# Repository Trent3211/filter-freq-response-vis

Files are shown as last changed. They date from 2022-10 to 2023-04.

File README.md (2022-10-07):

# Filter Frequency Response Visualizer
GitHub repo for SDSU Senior Design Team 18, Filter Frequency Response Visualizer, or FFRV

## SYSTEM DESCRIPTION

The FFRV system  will be a test box used for measuring the frequency response of a user-provided passive filter. Once started, the system will apply a frequency sweep across an inputted filter, then measure the filter output gain and phase shift using analog computations, inputted to an Arduino Due microcontroller. Thus, this FFRV system will calculate the Bode plots for a real-world filter. The purpose of the FFRV system is to allow students, hobbyists, and other casual filter-designers a rapid way to gain insight into simple filters, such as what frequencies they pass or reject. As such, the FFRV system will be designed to be straightforward to use. It shall have a box face with only a select few clearly-labeled inputs, and output a data file of the measurements to the user computer, connected over USB to the test box. The functional components in this system will include a procured waveform generator, a PCB for distributing power and performing analog analysis on filter magnitude and phase, an Arduino Due for converting the analog values to digital and controlling the waveform generator, and a NET application which will provide the user an interface to work with the system.

## USING GITHUB

### Basic Operation: 

Git is both local version control (local) and also cloud version control (remote). Version control is logging how changes are made to documents (think google docs history) so that way changes can be managed. This is useful in code, where you may have a working solution but you want to add features to it, so "committing" that version to a history log allows you to make changes, and always have a successful solution to return to. Basically, git is a way to log changes you make files, and then upload them to the cloud (have them stored virtually, rather than locally). That's the basic operation. There is more features that will be used, but at its most basic operation its changing files and then logging those changes. 

### Install Git:

__Create Git Repo Folder__
<br>
Purely for containment sakes, you may want to create a folder for holding all your GitHub repos. This is optional. If you already have a folder, then you have no need to create a new folder. I (Trent) would suggest creating a folder titled "GitHub-Repos" in your Documents folder on your computer. You can create that folder using the following CLI commands. (To open the terminal, type "Command Prompt" in the search function on your windows machine, then click on the application)
```
cd Documents
mkdir GitHub-Repos
cd GitHub-Repos
```
__Add the repository__
<br>
Go to the desired directory (if you followed the steps in "Create Git Repo Folder", you will already be in the desired folder) and clone the repository. The comand will look like the following
```
git clone https://github.com/Trent3211/filter-freq-response-vis.git <Optional: What you'd like the document to be named>
```
Sections wrapped by \< \> will want to be replaced by what is referred to in the section. You should be able to now see a folder with the title you provided in the `<Optional: ...>` section, or it will be titled filter-freq-reponse-vis. You can view this in your file explorer, or by using the `dir` command in the Terminal (Command Prompt). To verify that the repository was properly imported, open the folder using the Windows File explorer. Check the folder for the README.md file. Its contents should match this file. 

### Creating a commit: 

To use Git, you'll link your local to the remote. As you make changes to the whatever files you're editing (NET application, INO file, KiCAD schematic, LTSpice simulation, etc.) you'll want to mark good changes. You mark these changes with a "commit". Committing works in three phases. First, you add the files you want to a new commit (using command line interface arguments, or CLI). Second, you'll "commit" these changes to your local git with a message that describes the changes that we're made from the previous commit to the current commit (there is a standardized way for creating commit messages), using the CLI. Third, you will "push" your local changes to the remote, again using the CLI. The steps and their associated CLI arguments are shown below:
<br>

__0a) Go to repository:__ `cd <local file path for github repo> `
<br>
__0b) Pull any new changes:__ `git fetch`
<br>
__1) Add Files:__ `git add <file name1> <file name2> ... <file name x> `
<br>
-> NOTE: Use `git status` to see what changes you've made to files. Those that have been edited will appear in red. After you've added them, if you run `git status` again they should appear green.
<br>
__2) Create Log Message:__ `git commit `
<br>
-> NOTE: This will open the default text editor, "Vim". Vim slightly terrifies me, so I would recommend switching your default editor to Notepad. To set it to that text editor, see "Other Helpful CLI". See notes on creating an effective commit message in the section below
<br>
__3) Push Changes:__ `git push -u origin`
<br>
-> NOTE: origin refers to the cloud repository, as it is the first instantiation of the github repo. 
<br>
<br>
_Commit Message Best Practice_
<br>
There are two parts to a commit message: the subject header and a description. A subject header should encapsulate what was changed in the commit using 50 characters or less. If there is a lot more detail necessary to encapsulate the full picture, that's what the description is used for. Best practice for the subject header is to use the imperative tense. Examples include `Test new data`, or `Rewire ground and power planes`. A subject header should be formatted such that someone reading could read it as "If applied, this commit will ...", followed by the subject header. Thus, the following examples would read "This commit will: Test new data" or "This commit will: Rewire ground and power planes". 
<br>
After writing the subject header, two lines breaks will separate the subject header from the description. The description may add more detail not included in the subject header, reasoning for why the commit was needed, include details about testing and verification steps, or detail errors that were encountered with the version in the commit that will need to be fixed in future commits. Wrap each line of the description after 72 characters, otherwise it will be hard to read using the CLI. More detail on commit messages can be found here [https://gist.github.com/robertpainsi/b632364184e70900af4ab688decf6f53]. A good commit message may look like the following (the sections preceded by # are autogenerated by Git. They can be left in, they will not be included when viewing the message in the future):
```
Rewire ground and power planes

A previous commit had the ground and power planes connected to the same 
netlist. However, there are still some serious ratnests that may 
introduce noise. An issue has been added to the GitHub to address it.
# Please enter the commit message for your changes. Lines starting
# with '#' will be ignored, and an empty message aborts the commit.
#
# On branch fake-branch
# Your branch is up to date with 'origin/fake-branch'.
#
# Changes to be committed:
#       new file:   fake-file
```

### Creating and merging a branch

As we set up issues (think spots of development in achieving our long term milestones) in GitHub and try to solve them, we'll want to create new branches to address them. Branching keeps the main tree clean as solutions develop, so that they are only added into the `main` branch when they are finished being developed and have been reviewed by other members of the team. The naming convention for a branch is the issue number, followed by an underscore, and a 1 to 3 word description of what changes the branch encapsulates/will encapsulate. For example, a good name for a branch that addresses issue 0 of team members getting to know each other would be `0_starbucks_meeting`. Be sure to always branch from the main branch, rather than form other branches. This will keep the logging and version control easier to follow. The steps for creating a branch locally and publishing to the remote are shown below:
<br>
<br>
__0a) Update to the remote:__ 
<br>
Run `git fetch` to update your local repository with changes with those made in the remote (the online repository that we all access). Now run `git status` to see how many commits above or behind you are. If you have not made any changes that haven't yet been committed, run `git pull`. You will now be up-to-date with the remote and ready to proceed. 
<br>
__0b) Set to `main` branch:__ 
<br> Run `git status` using the CLI to make sure you are on the main branch. The first line of the text output should detail which branch you are on. If you are not on the main branch, run `git checkout main`. The output in this case should now be:
```
Switched to branch 'main'
Your branch is up to date with 'origin/main'.
```
__1) Create a new local branch:__ 
<br>
To create a new branch, there are two sets of commands you can choose. The first create a new branch off of the current branch, followed by a checkout command to switch to it. First run `git branch <Branch-Name>`. You can verify the branch was properly created by running `git branch`, which will list all available branches. Next, switch to the branch by running `git checkout <Branch-Name>`. The second method for creating a new branch both creates and switches to a branch in one command. This is `git checkout -b <Branch-Name>`. Only one of these two methods may be used to create and switch to a new branch--not both.
<br>
__2) Push branch to remote:__ 
<br>
In order to set up the branch so that it is remotely tracked, run `git push -u origin <Branch-Name>`. Now, when commits are made and pushed, they will be pushed to this branch in the remote. You are now free to add/change files and create commits
<br>
__3) Pull Request:__ 
<br>
The final part in a branches lifecycle is its death, which happens by merging it into the `main` branch. A merge into the `main` branch is called a pull request. It's poorly named, but there's no changing what GitHub refers to it as so so be it. You can find the list of branches on GitHub website by clicking "\<\> Code" when in the repositor folder. Click on the "Branches" tab. When you click on this, you will see a list of branches. Click on the "Pull Request" button next to the desired branch. Add a comment providing a paragraph description of what has been changed, and add reviewers for who should review the changes before its merged into `main`. Publish once you are ready.
<br>
### Other Helpful CLI:
`git checkout <branch name>`
<br>
`git branch`
Lists all branches currently visible on the local machine. (Other branches in the remote will be accessible using a `git checkout`, but may not be visible using git branch)
`git log` 
See all commits in the repository (if you've made new commits, these should show up here. It zhould also be synced with the remote if you've run `git fetch` and `git pull`)

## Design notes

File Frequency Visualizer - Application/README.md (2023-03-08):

# FFRV - Filter Frequency Response Visualizer

FFRV is a Python application for testing and analyzing the performance of a device under test (DUT) using a Due microcontroller. 

## Installation

To install the FFRV application, please ensure Python is installed as well as all required dependencies using the Setup.py script:

```python setup.py install```

## Running the Application

To run the FFRV application, execute the ffrv.py script using Python:

```python ffrv.py```

The application will launch and present a user interface for connecting to and testing a DUT using the Due microcontroller. The Connect/Disconnect buttons can be used to establish and terminate a connection to the Due, and the Sweep option in the top object window menu can be used to initiate a sweep of the DUT's response.

During testing, the application will present a real-time plot and table of the raw and running average data from the Due. Error testing conditions have been used for debugging and monitoring for invalid data. Currently, all debug notifications and information is printed in the user's executed environment (cmd, VScode terminal, etc).

## License

FFRV is licensed under the MIT License. See the LICENSE file for more information.

## Acknowledgments

The FFRV application was developed by Jarrod Rowson and as part of Filter Frequency Response Visualizer for Team 18 at San Diego State University. Special thanks to [Dr. Ashrafi].

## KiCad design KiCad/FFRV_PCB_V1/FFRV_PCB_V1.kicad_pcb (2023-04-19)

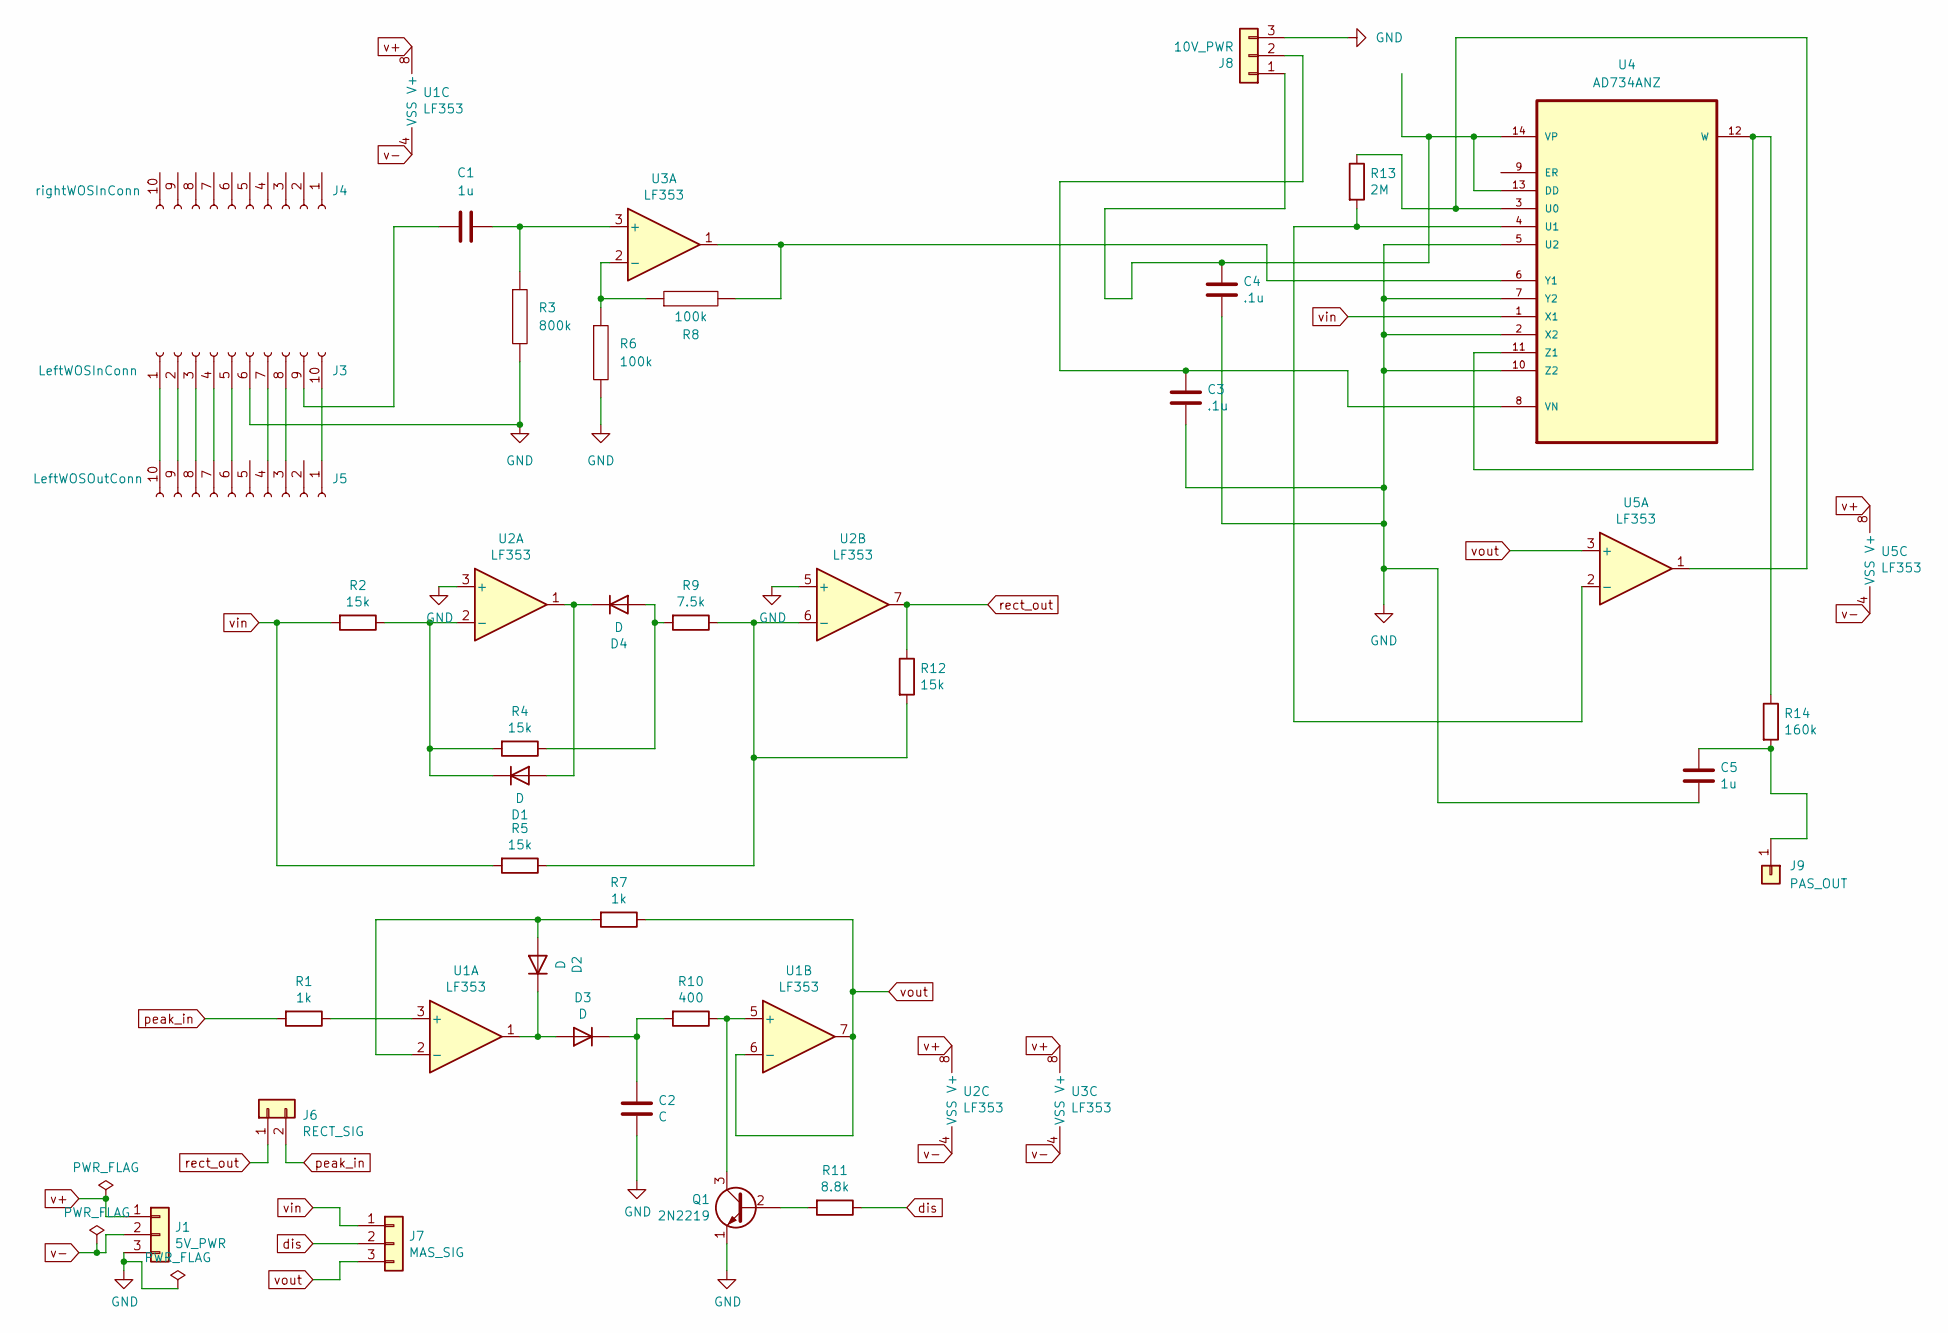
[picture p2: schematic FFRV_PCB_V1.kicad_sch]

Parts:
C1: 1u; C_Axial_L19.0mm_D7.5mm_P25.00mm_Horizontal
C2: C; C_Axial_L12.0mm_D6.5mm_P15.00mm_Horizontal
C3, C4: .1u; C_Disc_D3.0mm_W1.6mm_P2.50mm
C5: 1u; C_Axial_L22.0mm_D10.5mm_P27.50mm_Horizontal
D1, D2, D3, D4: D; R_Axial_DIN0207_L6.3mm_D2.5mm_P10.16mm_Horizontal
J1: 5V_PWR; PinSocket_1x03_P2.54mm_Vertical
J3: LeftWOSInConn; PinHeader_1x10_P2.54mm_Vertical
J4: rightWOSInConn; PinHeader_1x10_P2.54mm_Vertical
J5: LeftWOSOutConn; PinHeader_1x10_P2.54mm_Vertical
J6: RECT_SIG; PinSocket_1x02_P2.54mm_Vertical
J7: MAS_SIG; PinSocket_1x03_P2.54mm_Vertical
J8: 10V_PWR; PinSocket_1x03_P2.54mm_Vertical
J9: PAS_OUT; PinSocket_1x01_P2.54mm_Vertical
Q1: 2N2219; TO-39-3
R1, R7: 1k; R_Axial_DIN0207_L6.3mm_D2.5mm_P10.16mm_Horizontal
R2, R4, R5, R12: 15k; R_Axial_DIN0207_L6.3mm_D2.5mm_P10.16mm_Horizontal
R3: 800k; R_Axial_DIN0207_L6.3mm_D2.5mm_P10.16mm_Horizontal
R6, R8: 100k; R_Axial_DIN0207_L6.3mm_D2.5mm_P10.16mm_Horizontal
R9: 7.5k; R_Axial_DIN0207_L6.3mm_D2.5mm_P10.16mm_Horizontal
R10: 400; R_Axial_DIN0207_L6.3mm_D2.5mm_P10.16mm_Horizontal
R11: 8.8k; R_Axial_DIN0207_L6.3mm_D2.5mm_P10.16mm_Horizontal
R13: 2M; R_Axial_DIN0207_L6.3mm_D2.5mm_P10.16mm_Horizontal
R14: 160k; R_Axial_DIN0207_L6.3mm_D2.5mm_P10.16mm_Horizontal
U1, U2, U3, U5: LF353; DIP-8_W7.62mm
U4: AD734ANZ; DIP-14_W7.62mm; MPN AD734ANZ

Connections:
GND: C2.2, C3.2, C4.2, C5.2, J1.3, J3.6, J8.3, Q1.1 (E), R3.2, R6.2, U2.3 (+), U2.5 (+), U4.2 (X2), U4.5 (U2), U4.7 (Y2), U4.10 (Z2)
unnamed: C1.1, J3.9
unnamed: C1.2, R3.1, U3.3 (+)
unnamed: C2.1, D3.1 (K), R10.2
unnamed: C3.1, J8.2, U4.8 (VN)
unnamed: C4.1, J8.1, U4.13 (DD), U4.14 (VP)
unnamed: C5.1, J9.1, R14.2
unnamed: D1.1 (K), R2.1, R4.2, U2.2 (-)
unnamed: D1.2 (A), D4.1 (K), U2.1
unnamed: D2.1 (K), D3.2 (A), U1.1
unnamed: D2.2 (A), R7.2, U1.2 (-)
unnamed: D4.2 (A), R4.1, R9.2
unnamed: J3.1, J5.10
unnamed: J3.2, J5.9
unnamed: J3.3, J5.8
unnamed: J3.4, J5.7
unnamed: J3.5, J5.6
unnamed: J3.7, J5.4
unnamed: J3.8, J5.3
unnamed: J3.10, J5.1
unnamed: Q1.2 (B), R11.2
unnamed: Q1.3 (C), R10.1, U1.5 (+)
unnamed: R1.1, U1.3 (+)
unnamed: R6.1, R8.1, U3.2 (-)
unnamed: R8.2, U3.1, U4.6 (Y1)
unnamed: R5.1, R9.1, R12.2, U2.6 (-)
unnamed: R13.1, U4.3 (U0), U5.1
unnamed: R13.2, U4.4 (U1), U5.2 (-)
unnamed: R14.1, U4.11 (Z1), U4.12 (W)
dis: J7.2, R11.1
peak_in: J6.2, R1.2
rect_out: J6.1, R12.1, U2.7
v+: J1.1, U1.8 (V+), U2.8 (V+), U3.8 (V+), U5.8 (V+)
v-: J1.2, U1.4 (VSS), U2.4 (VSS), U3.4 (VSS), U5.4 (VSS)
vin: J7.1, R2.2, R5.2, U4.1 (X1)
vout: J7.3, R7.1, U1.6 (-), U1.7, U5.3 (+)

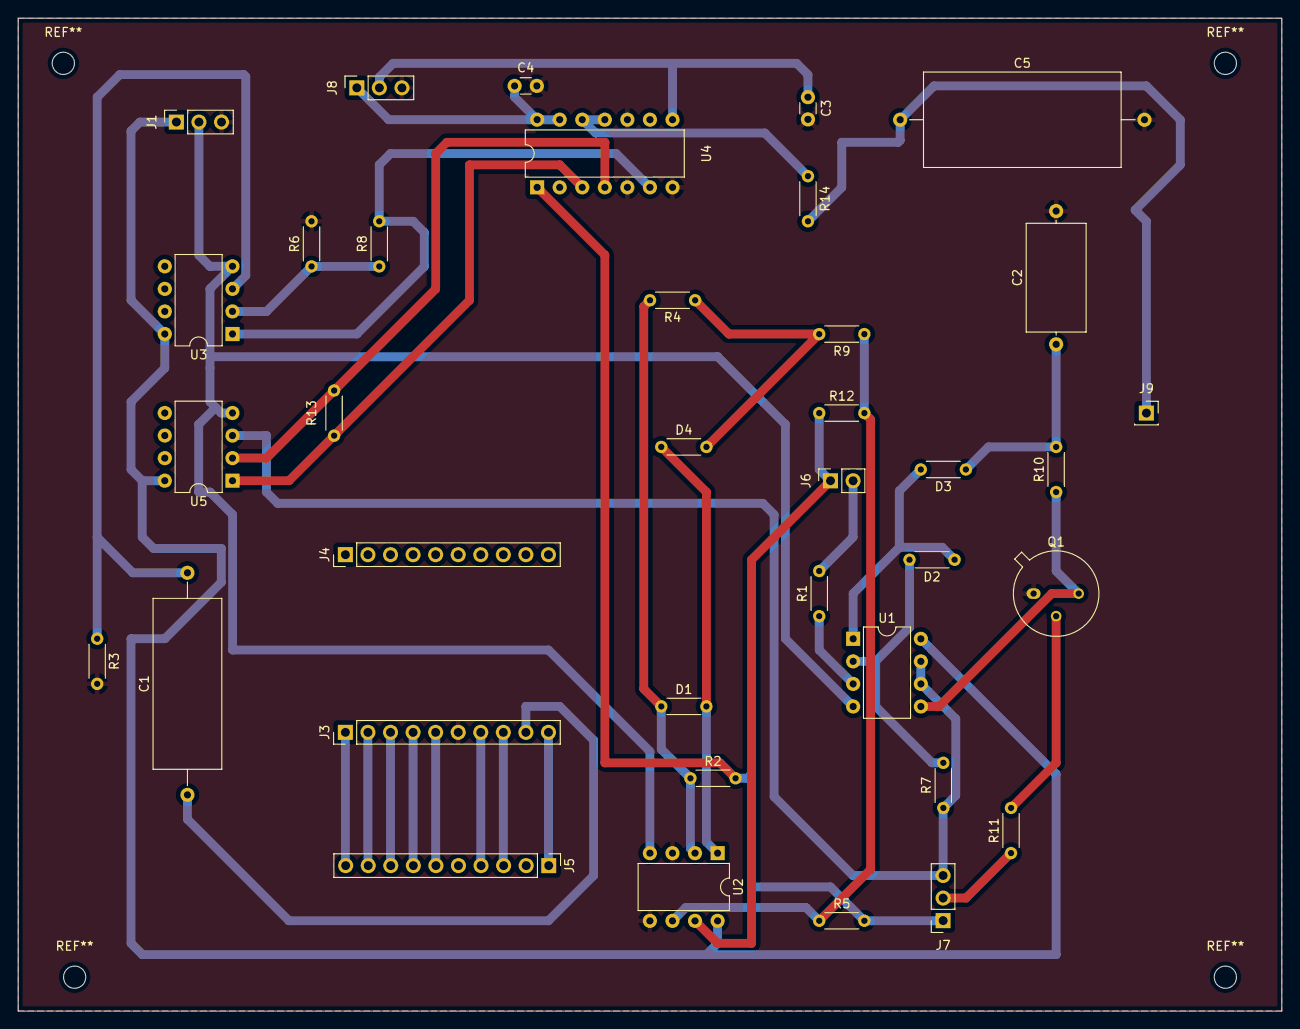
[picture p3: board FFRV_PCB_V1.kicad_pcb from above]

Board: 2 copper layers, 142.2 x 111.8 mm, 37 parts (0 on the bottom side), 36 nets.

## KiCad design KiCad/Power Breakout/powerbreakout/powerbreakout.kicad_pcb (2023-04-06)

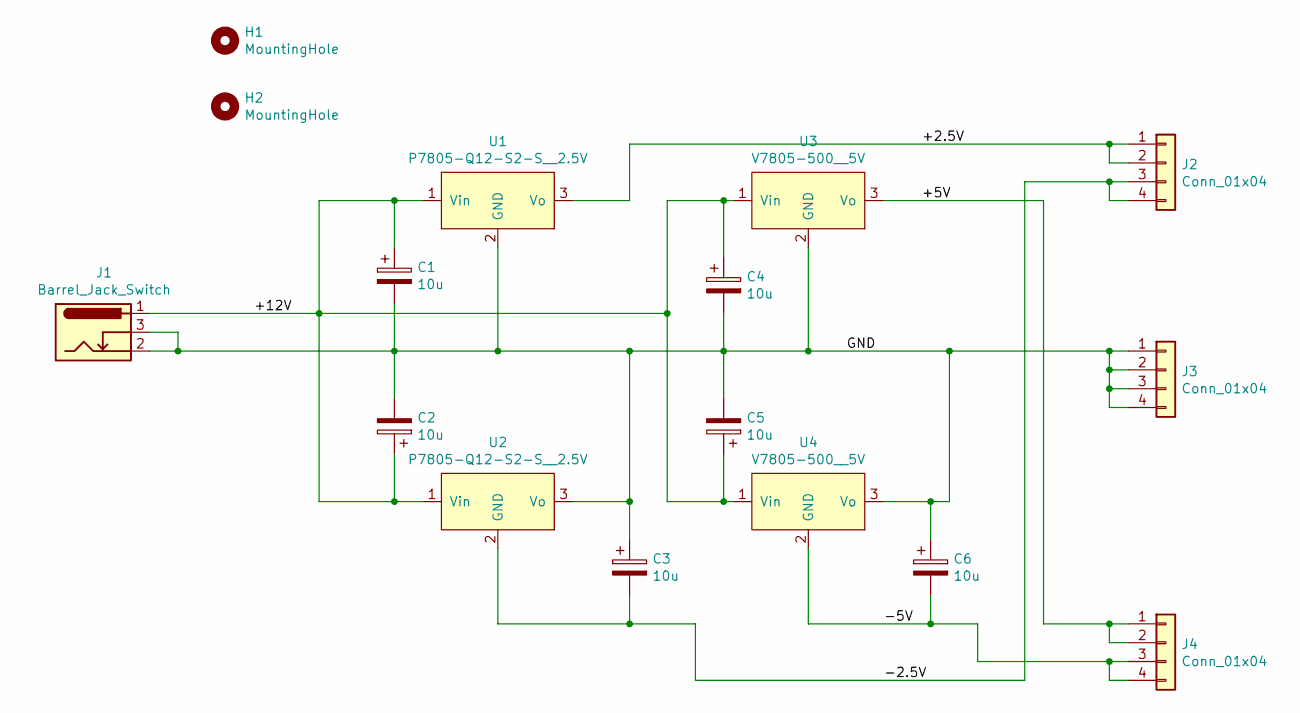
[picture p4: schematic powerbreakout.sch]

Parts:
C1, C2, C3, C4, C5, C6: 10u; C_Radial_D6.3mm_H7.0mm_P2.50mm
H1, H2: MountingHole; MountingHole_2.5mm
J1: Barrel_Jack_Switch; BarrelJack_Horizontal
J2, J3, J4: Conn_01x04; PinSocket_1x04_P2.54mm_Vertical
U1, U2: P7805-Q12-S2-S__2.5V; SIP3_11.6x8.5mm
U3, U4: V7805-500__5V; SIP3_11.6x8.5mm

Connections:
/+2.5V: J2.1, J2.2, U1.3 (Vo)
/+5V: J4.1, J4.2, U3.3 (Vo)
/+12V: C1.1, C2.1, C4.1, C5.1, J1.1, U1.1 (Vin), U2.1 (Vin), U3.1 (Vin), U4.1 (Vin)
/-2.5V: C3.2, J2.3, J2.4, U2.2 (GND)
/-5V: C6.2, J4.3, J4.4, U4.2 (GND)
/GND: C1.2, C2.2, C3.1, C4.2, C5.2, C6.1, J1.2, J1.3, J3.1, J3.2, J3.3, J3.4, U1.2 (GND), U2.3 (Vo), U3.2 (GND), U4.3 (Vo)

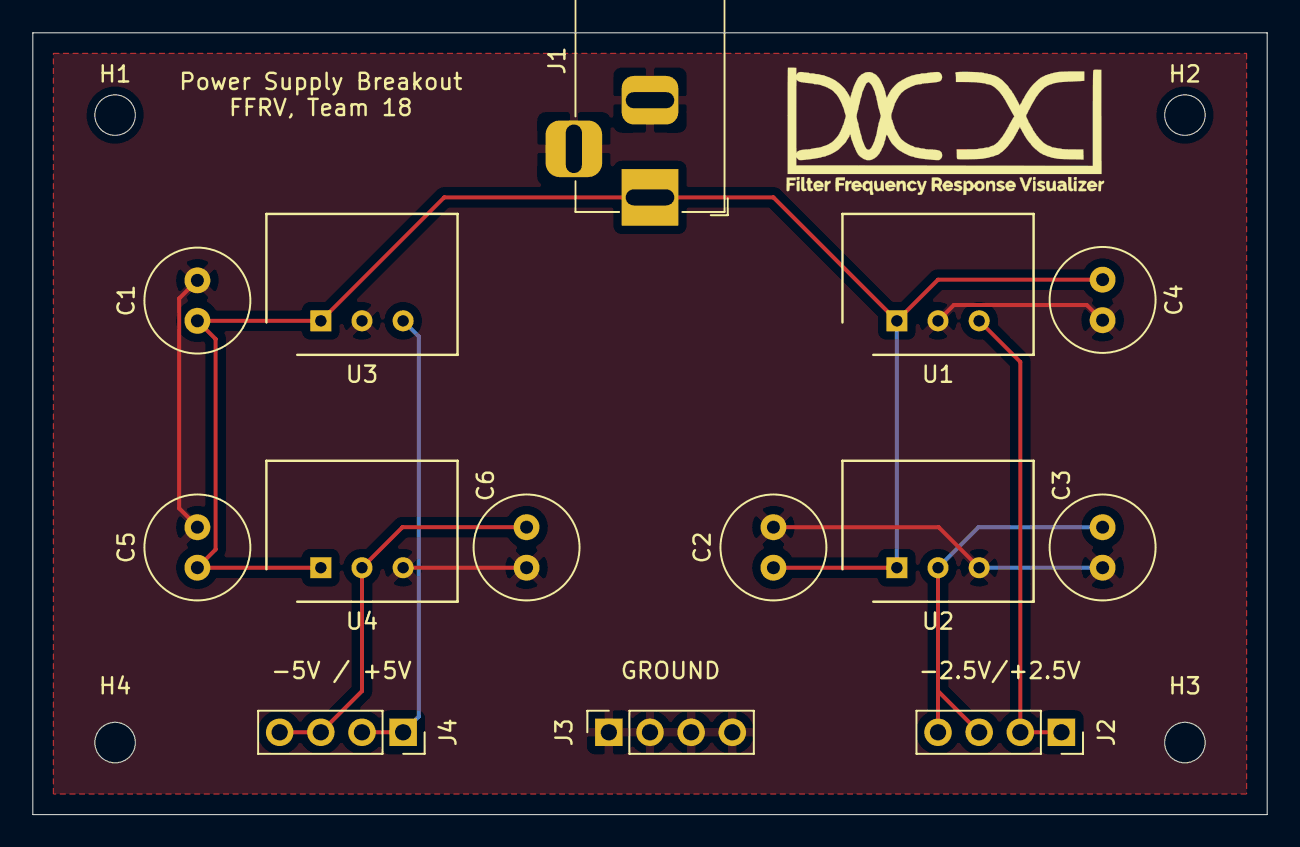
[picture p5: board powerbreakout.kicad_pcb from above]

Board: 2 copper layers, 76.2 x 48.3 mm, 18 parts (0 on the bottom side), 6 nets.

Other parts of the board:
H3, H4: MountingHole; MountingHole_2.5mm

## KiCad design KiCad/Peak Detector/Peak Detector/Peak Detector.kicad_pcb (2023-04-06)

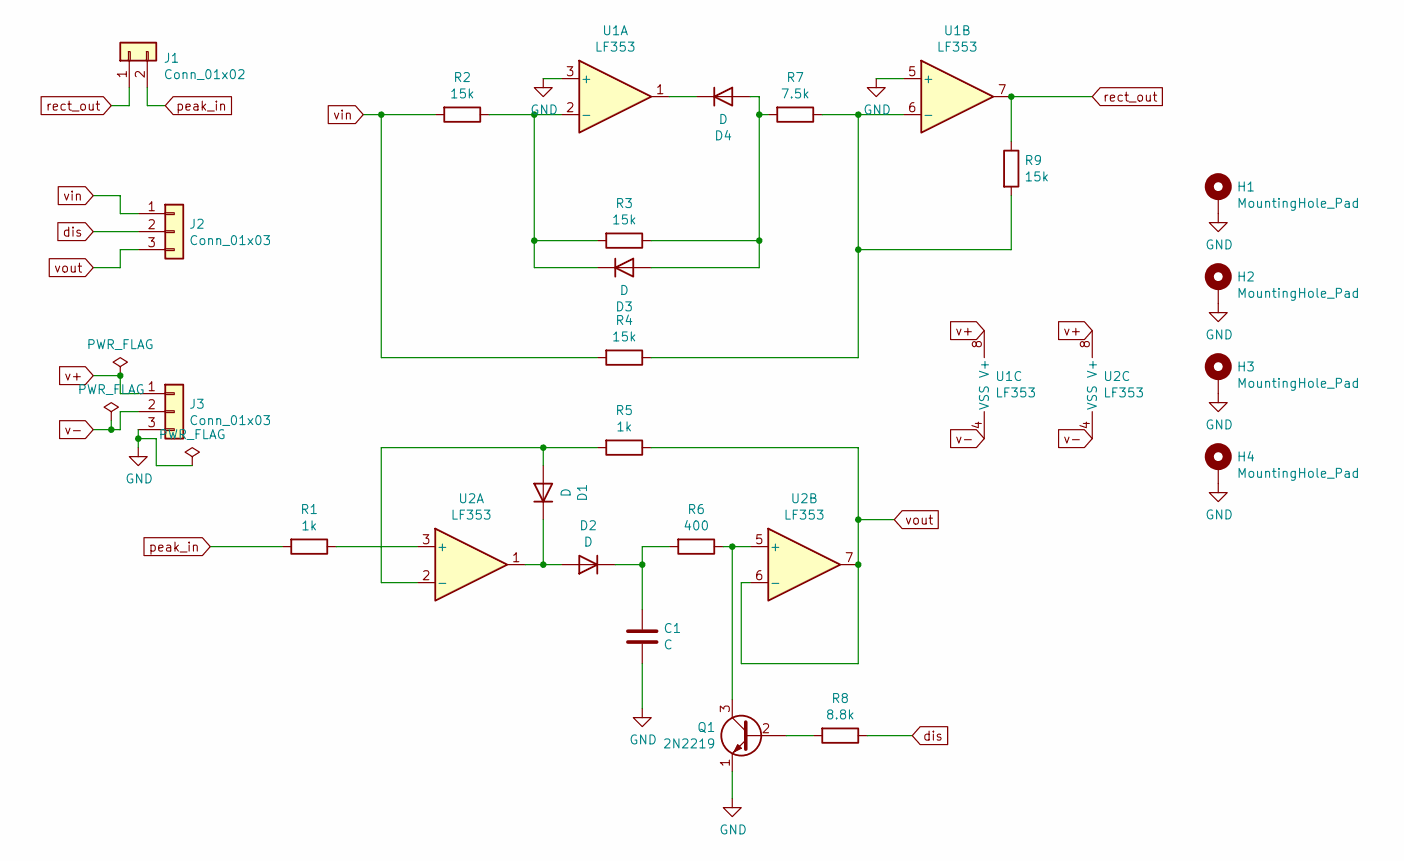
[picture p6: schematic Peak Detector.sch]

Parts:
C1: C; C_2225_5664Metric_Pad1.80x6.60mm_HandSolder
D1, D2, D3, D4: D; D_2512_6332Metric_Pad1.52x3.35mm_HandSolder
H1, H2, H3, H4: MountingHole_Pad; MountingHole_2.5mm
J1: Conn_01x02; PinSocket_1x02_P2.54mm_Vertical
J2, J3: Conn_01x03; PinSocket_1x03_P2.54mm_Vertical
Q1: 2N2219; TO-39-3
R1, R5: 1k; R_2512_6332Metric_Pad1.40x3.35mm_HandSolder
R2, R3, R4, R9: 15k; R_2512_6332Metric_Pad1.40x3.35mm_HandSolder
R6: 400; R_2512_6332Metric_Pad1.40x3.35mm_HandSolder
R7: 7.5k; R_2512_6332Metric_Pad1.40x3.35mm_HandSolder
R8: 8.8k; R_2512_6332Metric_Pad1.40x3.35mm_HandSolder
U1, U2: LF353; DIP-8_W7.62mm

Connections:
GND: C1.2, H1.1, H2.1, H3.1, H4.1, J3.3, Q1.1 (E), U1.3 (+), U1.5 (+)
unnamed: C1.1, D2.1 (K), R6.2
unnamed: D1.1 (K), D2.2 (A), U2.1
unnamed: D1.2 (A), R5.2, U2.2 (-)
unnamed: D3.1 (K), R2.1, R3.2, U1.2 (-)
unnamed: D3.2 (A), D4.2 (A), R3.1, R7.2
unnamed: D4.1 (K), U1.1
unnamed: Q1.2 (B), R8.2
unnamed: Q1.3 (C), R6.1, U2.5 (+)
unnamed: R1.1, U2.3 (+)
unnamed: R4.1, R7.1, R9.2, U1.6 (-)
dis: J2.2, R8.1
peak_in: J1.2, R1.2
rect_out: J1.1, R9.1, U1.7
v+: J3.1, U1.8 (V+), U2.8 (V+)
v-: J3.2, U1.4 (VSS), U2.4 (VSS)
vin: J2.1, R2.2, R4.2
vout: J2.3, R5.1, U2.6 (-), U2.7

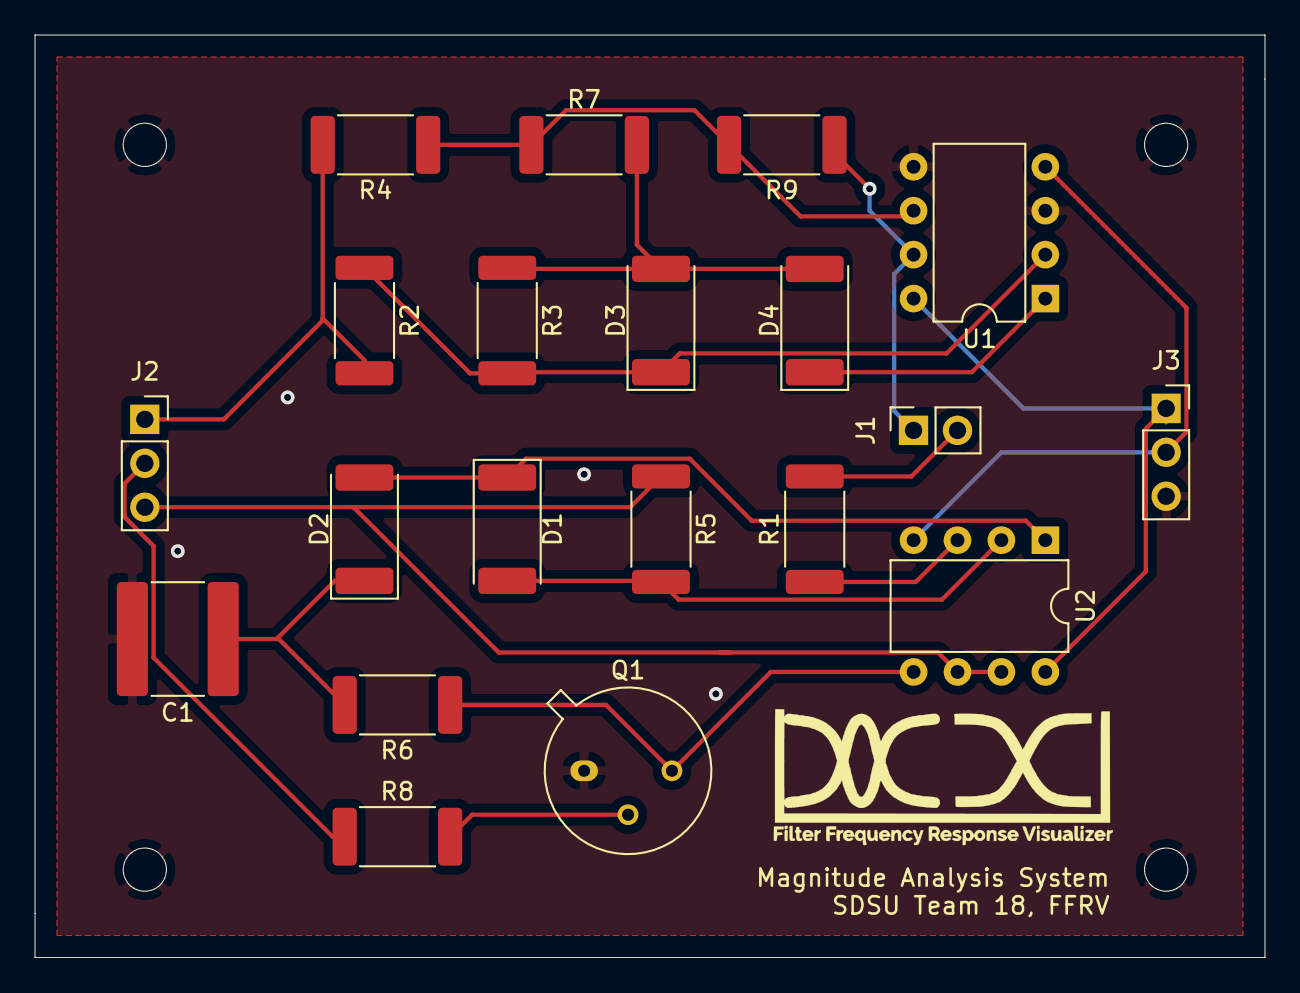
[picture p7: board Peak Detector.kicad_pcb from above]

Board: 2 copper layers, 71.1 x 53.3 mm, 24 parts (0 on the bottom side), 18 nets.

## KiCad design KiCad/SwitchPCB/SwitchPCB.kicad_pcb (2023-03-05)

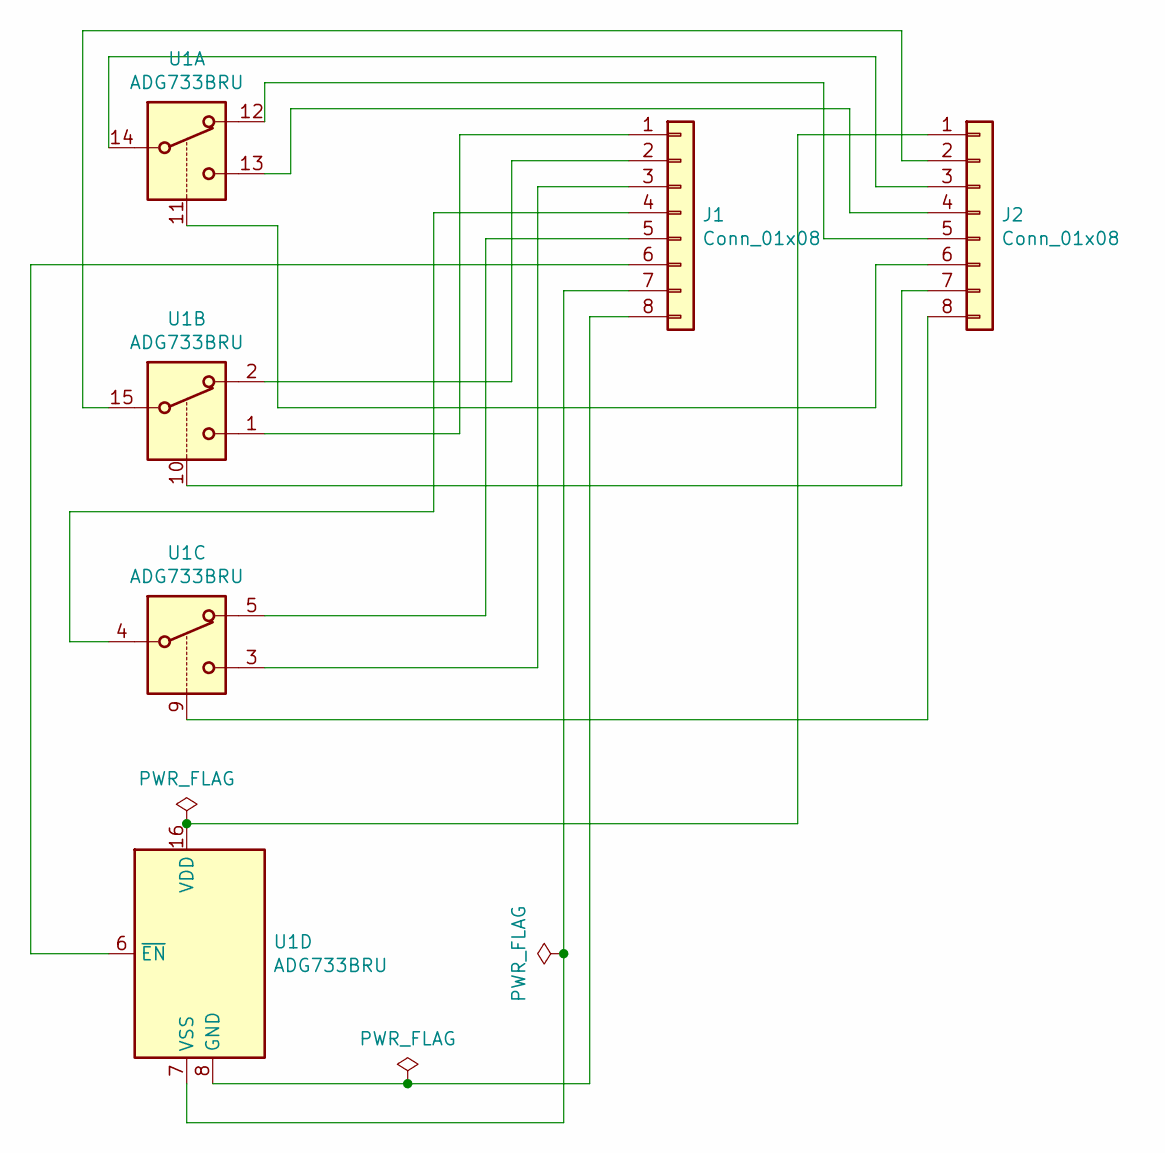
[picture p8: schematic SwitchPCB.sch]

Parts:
J1, J2: Conn_01x08; PinSocket_1x08_P2.54mm_Vertical
U1: ADG733BRU; TSSOP-16_4.4x5mm_P0.65mm

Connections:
unnamed: J1.1, U1.1
unnamed: J1.2, U1.2
unnamed: J1.3, U1.3
unnamed: J1.4, U1.4
unnamed: J1.5, U1.5
unnamed: J1.6, U1.6 (~EN)
unnamed: J1.7, U1.7 (VSS)
unnamed: J1.8, U1.8 (GND)
unnamed: J2.1, U1.16 (VDD)
unnamed: J2.2, U1.15
unnamed: J2.3, U1.14
unnamed: J2.4, U1.13
unnamed: J2.5, U1.12
unnamed: J2.6, U1.11
unnamed: J2.7, U1.10
unnamed: J2.8, U1.9

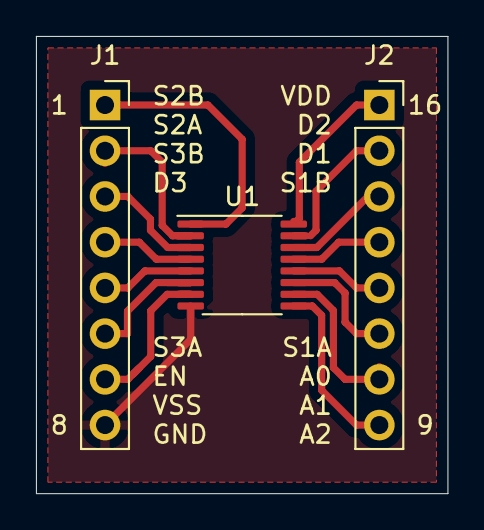
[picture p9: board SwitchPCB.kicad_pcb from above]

Board: 2 copper layers, 22.9 x 25.4 mm, 3 parts (0 on the bottom side), 16 nets.

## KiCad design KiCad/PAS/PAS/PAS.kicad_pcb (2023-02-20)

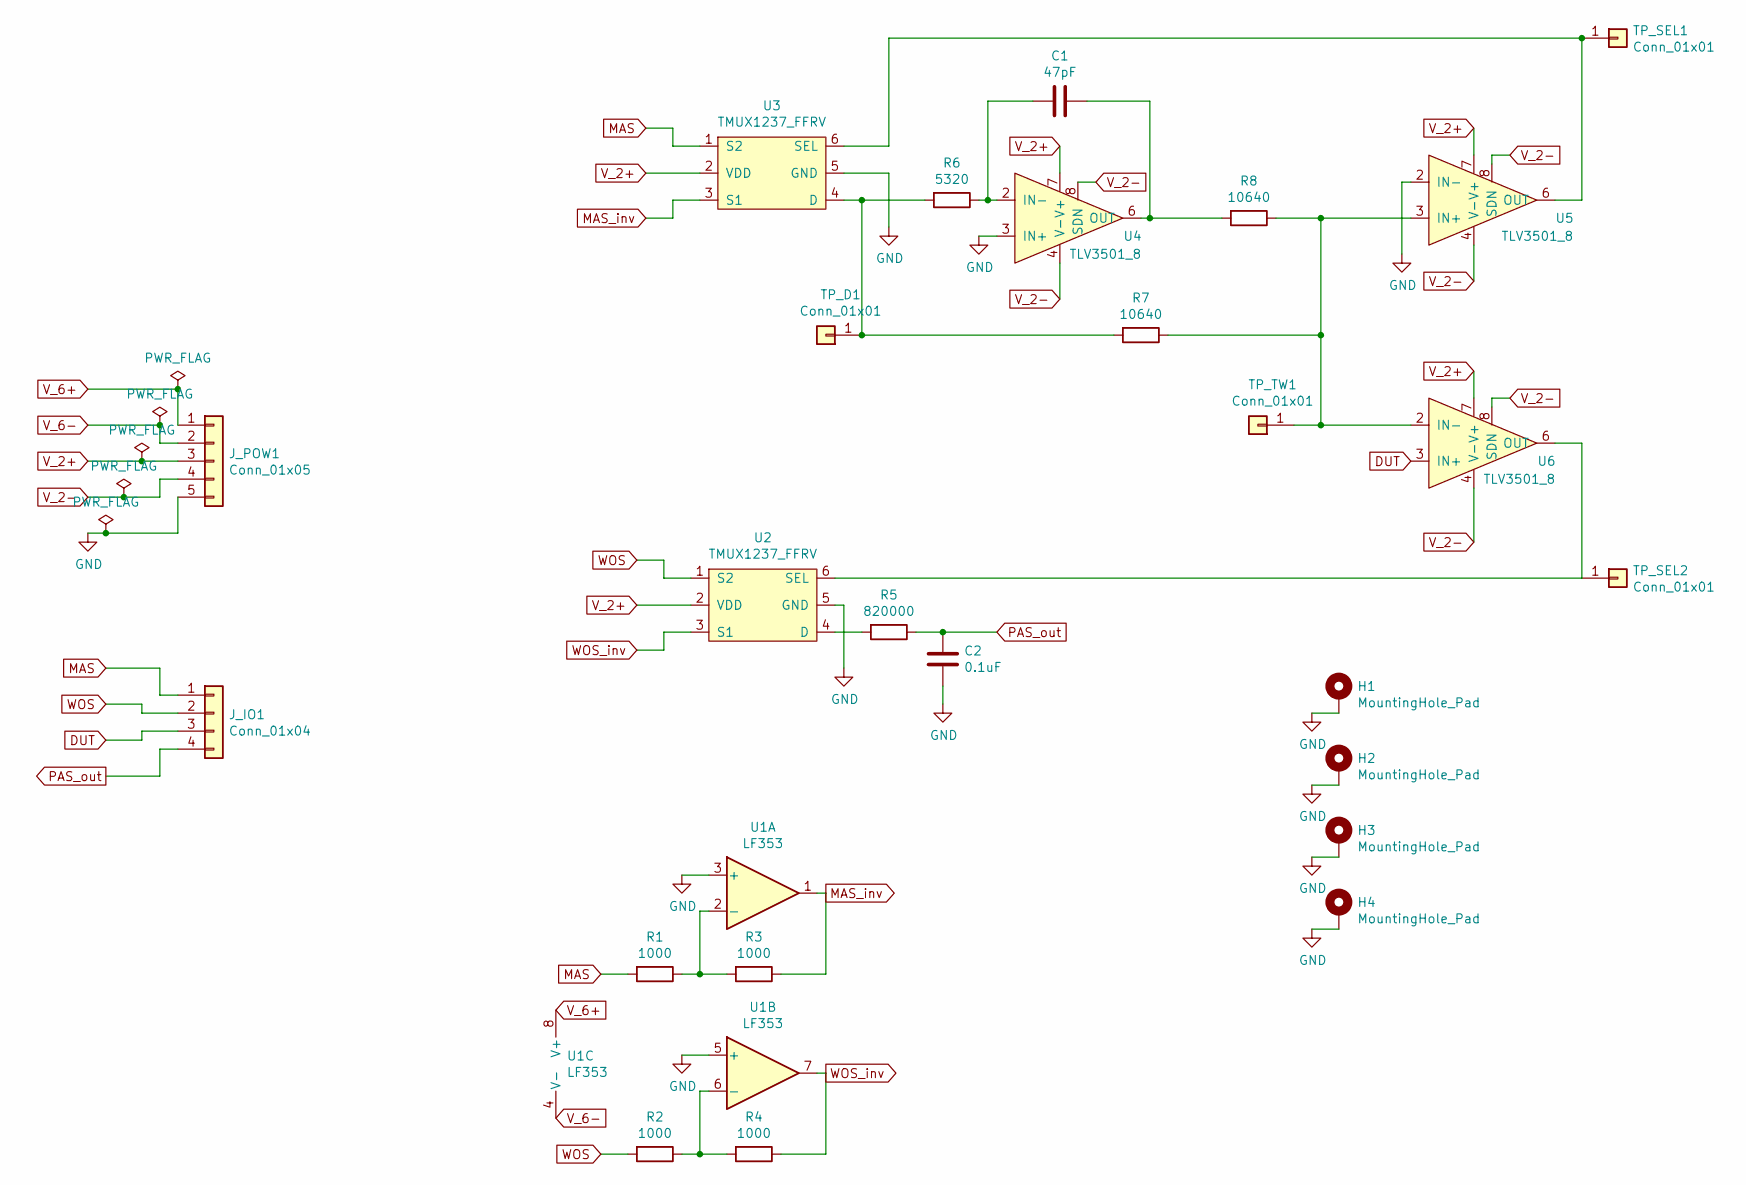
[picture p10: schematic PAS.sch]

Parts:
C1: 47pF; C_2225_5664Metric_Pad1.80x6.60mm_HandSolder
C2: 0.1uF; C_2225_5664Metric_Pad1.80x6.60mm_HandSolder
H1, H2, H3, H4: MountingHole_Pad; MountingHole_2.5mm_Pad
J_IO1: Conn_01x04; PinSocket_1x04_P2.54mm_Vertical
J_POW1: Conn_01x05; PinSocket_1x05_P2.54mm_Vertical
R1, R2, R3, R4: 1000; R_2512_6332Metric_Pad1.40x3.35mm_HandSolder
R5: 820000; R_2512_6332Metric_Pad1.40x3.35mm_HandSolder
R6: 5320; R_2512_6332Metric_Pad1.40x3.35mm_HandSolder
R7, R8: 10640; R_2512_6332Metric_Pad1.40x3.35mm_HandSolder
TP_D1: Conn_01x01; PinSocket_1x01_P2.54mm_Vertical
TP_SEL1, TP_SEL2: Conn_01x01; PinSocket_1x01_P2.54mm_Vertical
TP_TW1: Conn_01x01; PinSocket_1x01_P2.54mm_Vertical
U1: LF353; DIP-8_W7.62mm
U2, U3: TMUX1237_FFRV; SOT-23-6_Handsoldering
U4, U5, U6: TLV3501_8; SOIC-8_3.9x4.9mm_P1.27mm

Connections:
DUT: J_IO1.3, U6.3 (IN+)
GND: C2.2, H1.1, H2.1, H3.1, H4.1, J_POW1.5, U1.3 (+), U1.5 (+), U2.5 (GND), U3.5 (GND), U4.3 (IN+), U5.2 (IN-)
MAS: J_IO1.1, R1.2, U3.1 (S2)
MAS_inv: R3.1, U1.1, U3.3 (S1)
unnamed: C1.1, R8.2, U4.6 (OUT)
unnamed: C1.2, R6.1, U4.2 (IN-)
unnamed: R1.1, R3.2, U1.2 (-)
unnamed: R2.1, R4.2, U1.6 (-)
unnamed: R5.2, U2.4 (D)
unnamed: R6.2, R7.2, TP_D1.1, U3.4 (D)
unnamed: R7.1, R8.1, TP_TW1.1, U5.3 (IN+), U6.2 (IN-)
unnamed: TP_SEL1.1, U3.6 (SEL), U5.6 (OUT)
unnamed: TP_SEL2.1, U2.6 (SEL), U6.6 (OUT)
PAS_out: C2.1, J_IO1.4, R5.1
V_2+: J_POW1.3, U2.2 (VDD), U3.2 (VDD), U4.7 (V+), U5.7 (V+), U6.7 (V+)
V_2-: J_POW1.4, U4.4 (V-), U4.8 (SDN), U5.4 (V-), U5.8 (SDN), U6.4 (V-), U6.8 (SDN)
V_6+: J_POW1.1, U1.8 (V+)
V_6-: J_POW1.2, U1.4 (V-)
WOS: J_IO1.2, R2.2, U2.1 (S2)
WOS_inv: R4.1, U1.7, U2.3 (S1)

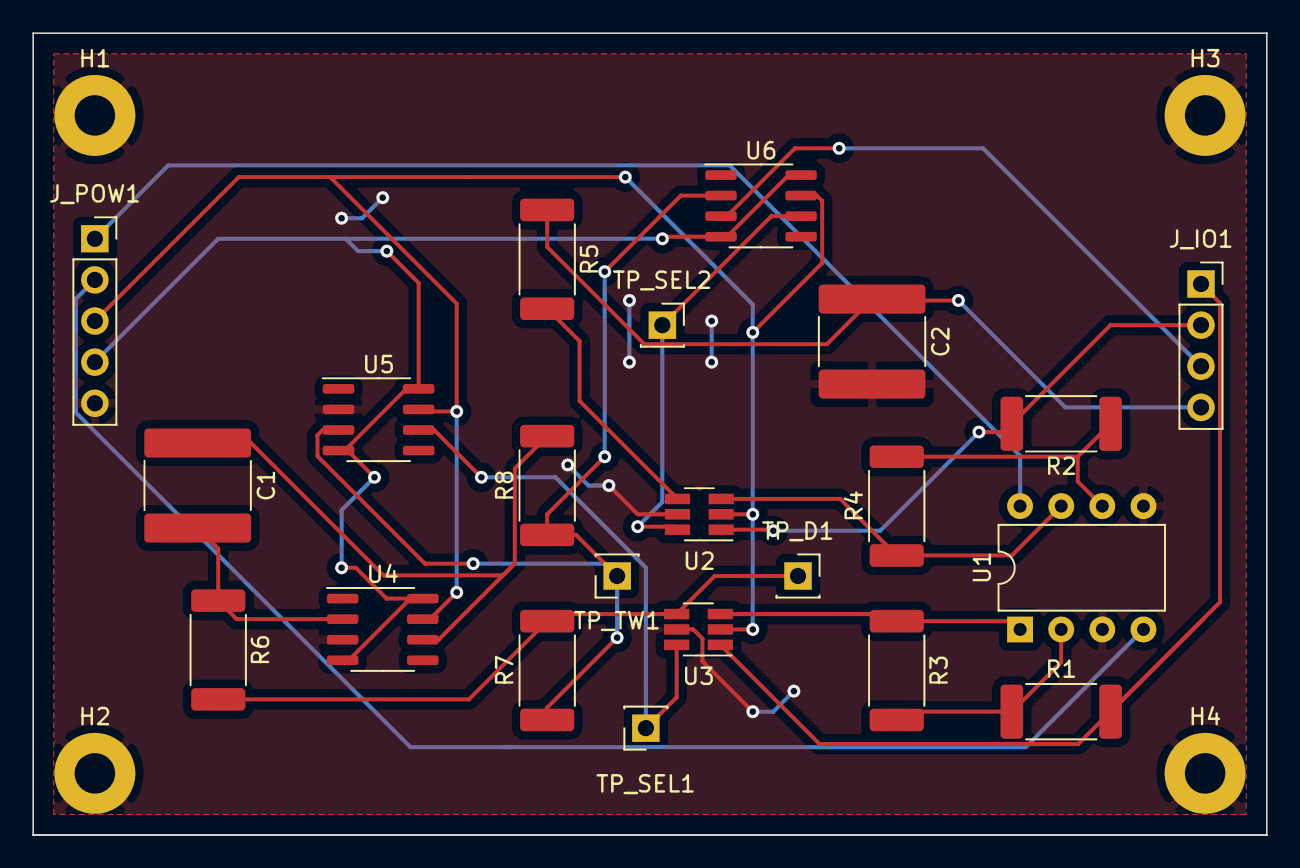
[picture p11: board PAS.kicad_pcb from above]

Board: 2 copper layers, 76.2 x 49.5 mm, 26 parts (0 on the bottom side), 20 nets.

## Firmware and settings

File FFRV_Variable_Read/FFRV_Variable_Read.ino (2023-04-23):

// These define's must be placed at the beginning before #include "SAMDUETimerInterrupt.h"
#define TIMER_INTERRUPT_DEBUG         0
#define _TIMERINTERRUPT_LOGLEVEL_     0
#include "SAMDUETimerInterrupt.h"

#include <EF_AD9850.h>


#define SWEEP_DEC1_US        150000   //  150 ms
#define SWEEP_DEC2_US         15000   //  15  ms
#define SWEEP_DEC3_US          6000   //  1.5 ms

#define SAMP_DEC1_US          15000
#define SAMP_DEC2_US           1500
#define SAMP_DEC3_US            500 

#define START_FREQ               20
#define NUM_SAMPLES              10

#define DISCHARGE_PIN            12
#define TEST_PIN                  3
#define MAS_PIN                   7      // A0
#define PAS_PIN                   6      // A1

// led definitions
#define READY                     5
#define SWEEPING                  4
#define FAULT                     3

#define MODE_FINI                 2
#define MODE_SWEEP                1
#define MODE_WAIT                 0



EF_AD9850 AD9850(11, 10, 8, 9);    // D_CLK, FR_UQ, RST, DATA

uint16_t sweepInterruptID = 0;
uint16_t readInterruptID = 0;
uint8_t decadeNum = 0;
uint8_t mode = MODE_WAIT;


volatile uint32_t masBufferReg[NUM_SAMPLES];
volatile uint32_t pasBufferReg[NUM_SAMPLES];
volatile uint8_t sampleCount = 0;
volatile double freq = 0;
volatile bool dischargeSet = false;

String serialBuffer = "";
bool serialBufferFlag = false;




void setup() {
  Serial.begin(115200);
  AD9850.init();
  AD9850.reset();
  pinMode(DISCHARGE_PIN, OUTPUT);
  pinMode(TEST_PIN, OUTPUT);
  // led pin modes
  pinMode(READY, OUTPUT);
  pinMode(SWEEPING, OUTPUT);
  pinMode(FAULT, OUTPUT);
  
  digitalWrite(DISCHARGE_PIN, 0);
  digitalWrite(TEST_PIN, 0);
  digitalWrite(FAULT, HIGH);

  analogSetup(); // god why

  

  DueTimerInterrupt frequencySweepInterrupt = DueTimer.getAvailable();
  frequencySweepInterrupt.attachInterruptInterval(SWEEP_DEC1_US, sweepStep);
  sweepInterruptID = frequencySweepInterrupt.getTimerNumber();
  Serial.print("SweepID_START = ");
  Serial.println(sweepInterruptID);

  DueTimerInterrupt samplingInterrupt = DueTimer.getAvailable();
  samplingInterrupt.attachInterruptInterval(SAMP_DEC1_US, readAnalog);
  readInterruptID = samplingInterrupt.getTimerNumber();
  Serial.print("SampID_START = ");
  Serial.println(readInterruptID);

  while (1) {
    if (Serial.available() > 0){
      char charIn = Serial.read();
      if (charIn == '!'){
        digitalWrite(FAULT, LOW);
        digitalWrite(READY, HIGH);
        return;
      } 
    } 
  } 
}


void loop() {
  if (mode == MODE_WAIT){
    if (Serial.available() > 0){
      char charIn = Serial.read();
      if (charIn == 's'){
        mode = MODE_SWEEP;
        digitalWrite(READY, LOW);
        digitalWrite(SWEEPING, HIGH);
        digitalWrite(DISCHARGE_PIN, 0);
      } 
      else {
        return;
      }
    } 
    else { 
      return;
    }
  }
  else if (mode == MODE_FINI){
    digitalWrite(SWEEPING, LOW);
    digitalWrite(READY, HIGH);
    ffrvReset();
  }
  if (mode != MODE_SWEEP){
    return;
  }

  if (freq >= START_FREQ*100 && decadeNum < 3){
    updateSweepFrequency(SWEEP_DEC3_US);
    updateSampleFrequency(SAMP_DEC3_US);   
    decadeNum = 3;
    Serial.print("");
    //printSerialDecadeInfo(decadeNum);
  }
  else if (freq >= START_FREQ*10 && decadeNum < 2){
    updateSweepFrequency(SWEEP_DEC2_US);
    updateSampleFrequency(SAMP_DEC2_US);   
    decadeNum = 2;
    Serial.print("");
    //printSerialDecadeInfo(decadeNum);
  }
  else if (freq < START_FREQ*1 && decadeNum < 1){
    updateSweepFrequency(SWEEP_DEC1_US);
    updateSampleFrequency(SAMP_DEC1_US);
    decadeNum = 1;
    Serial.print("");
    //printSerialDecadeInfo(decadeNum);
  }
  if (mode == MODE_SWEEP && serialBufferFlag == false){
    Serial.print(serialBuffer);
    if (serialBufferFlag == false){
      serialBuffer = "";
    }
  }
}


void sweepStep() {
  if (mode != MODE_SWEEP){
    return;
  }
  if (freq > 30000){
    mode = MODE_FINI;
    return;
  }
  else if (freq < START_FREQ){
    digitalWrite(DISCHARGE_PIN, 1);
    freq = START_FREQ;
    AD9850.wr_serial(0, freq);
    Serial.print("");
    sampleCount = 0;
    digitalWrite(DISCHARGE_PIN, 0);
    return;
  }

  dischargeSet = true;
  digitalWrite(DISCHARGE_PIN, 1);
  serialBufferFlag = true;
  float newFreq = freq*pow(10, 0.04);
  AD9850.wr_serial(0, newFreq);
  
  for (uint8_t i = 0; i < sampleCount-2; i++){
    serialBuffer += String(freq);
    serialBuffer += ",";
    serialBuffer += String(masBufferReg[i]);
    serialBuffer += ",";
    serialBuffer += String(pasBufferReg[i]) + "\n";
  }
  sampleCount = 0;
  freq = newFreq; 
  serialBufferFlag = false;
  
  digitalWrite(DISCHARGE_PIN, 0);
  dischargeSet = false;
}


void readAnalog(){
  if (mode != MODE_SWEEP){
    return;
  }
  if (sampleCount < 2){
    sampleCount++;
    return;
  }
  
  if (!dischargeSet && sampleCount < NUM_SAMPLES){
    digitalWrite(TEST_PIN, 1);
    masBufferReg[sampleCount-2] = ADC->ADC_CDR[MAS_PIN];
    pasBufferReg[sampleCount-2] = ADC->ADC_CDR[PAS_PIN];
    sampleCount++;
    digitalWrite(TEST_PIN, 0);
  }
  
}


void ffrvReset() {
  mode = MODE_WAIT;
  freq = 0;
  decadeNum = 0;
  sampleCount = 0;
  digitalWrite(DISCHARGE_PIN, 1);
  Serial.println("e");
}


void analogSetup(){
  // SOURCE: https://forum.arduino.cc/t/direct-accessing-of-adc-registers/468806/4

  ADC->ADC_MR |= 0x80;  // Mode FREERUN
  ADC->ADC_CR = 2;        // Start converter                       
  ADC->ADC_CHER = 0xC0;   // Enabling channels 6 and 7 (A0 and A1)
}


void updateSweepFrequency(double microseconds){
  DueTimerInterrupt dueTimerInterrupt(sweepInterruptID);
  dueTimerInterrupt.attachInterruptInterval(microseconds, sweepStep);
  sweepInterruptID = dueTimerInterrupt.getTimerNumber();
}


void updateSampleFrequency(double microseconds){
  DueTimerInterrupt dueTimerInterrupt(readInterruptID);
  dueTimerInterrupt.attachInterruptInterval(microseconds, readAnalog);
  readInterruptID = dueTimerInterrupt.getTimerNumber();
}


void printSerialDecadeInfo(uint8_t dec){
  Serial.print("Decade");
  Serial.print(dec);
  Serial.print(" Start: ");
  Serial.print(micros());
  Serial.print(", frequency: ");
  Serial.println(freq);
}

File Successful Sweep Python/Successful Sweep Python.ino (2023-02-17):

#include <EF_AD9850.h>

// Define constants
const int MAX_BUFFER_SIZE = 1024;
const int SERIAL_BAUD_RATE = 115200;

// Define pin numbers used to communicate with module ESP
const int CLK_PIN = 0; // D3
const int FQUP_PIN = 2; // D4
const int RESET_PIN = 5; // D1
const int DATA_PIN = 4; // D2

// const int CLK_PIN = 11;
// const int FQUP_PIN = 10;
// const int RESET_PIN = 8;
// const int DATA_PIN = 9;

// Define variables
EF_AD9850 ad9850(CLK_PIN, FQUP_PIN, RESET_PIN, DATA_PIN);
double freqValue = 0;
double freqStart = 0;
double freqEnd = 0;
double freqStep = 0;
int sweepDelay = 0;
char frequencyString[MAX_BUFFER_SIZE];
int bufferPosition = 0;
char inputByte = 0;
int mode = 0;

// Compute the number of points per decade based on the starting and stopping frequencies
int getPointsPerDecade(double startFreq, double stopFreq, int numPoints) {
  double decades = log10(stopFreq / startFreq);
  int pointsPerDecade = (int)(numPoints / decades);
  return pointsPerDecade;
}


// Initialize the module and serial communication
void setup() {
  ad9850.init();
  ad9850.reset();
  Serial.begin(SERIAL_BAUD_RATE);
  memset(frequencyString, 0, sizeof(frequencyString));
}

// Main loop
void loop() {
  if (mode == 1) {
    int sensorValue = analogRead(A0);
    float voltage = sensorValue * (3.3 / 1023.0);
    Serial.print(freqValue);
    Serial.print(":");
    Serial.println(voltage);

    if (((freqStep > 0.0) && (freqValue + freqStep <= max(freqStart, freqEnd))) || ((freqStep < 0.0) && (freqValue + freqStep >= min(freqStart, freqEnd)))) {
      freqValue += freqStep;
    } else {
      ad9850.reset();
      mode = 0;
      Serial.println("Sweep finished");
    }
    ad9850.wr_serial(0, freqValue);
  } 

  while (Serial.available()) {
      inputByte = Serial.read();
      if (bufferPosition < sizeof(frequencyString)) {
        frequencyString[bufferPosition++] = inputByte;
      } else {
        bufferPosition = 0;
        inputByte = 0;
        memset(frequencyString, 0, sizeof(frequencyString));
        Serial.println("Command too long. Ignored.");
      }
      if (inputByte == 'r') {
        ad9850.reset();
        mode = 0;
        Serial.println("Sweep reset");
        memset(frequencyString, 0, sizeof(frequencyString));
        inputByte = 0;
        bufferPosition = 0;
      }
    }


  if (inputByte == '\n') {
    switch (frequencyString[0]) {
      case 's':
        char *freqEnd1, *freqEnd2;
        freqStart = abs(strtod(frequencyString + 2, &freqEnd1));
        freqEnd = abs(strtod(freqEnd1, &freqEnd2));
        freqStep = abs(strtod(freqEnd2, &freqEnd1));
        if (freqStep == 0) {
          Serial.println("Error: step size cannot be 0.");
          break;
        }
        sweepDelay = abs(atoi(freqEnd1));
        mode = 1;
        Serial.print("Sweep start frequency: ");
        Serial.print(freqStart);
        Serial.print(" end frequency: ");
        Serial.print(freqEnd);
        Serial.print(" step size: ");
        Serial.print(freqStep);
        Serial.print(" delay: ");
        Serial.println(sweepDelay);
        sweepDelay /= abs(freqEnd - freqStart) / freqStep;
        if (freqStart > freqEnd) {
          freqStep *= -1;
        }
        freqValue = freqStart;
        break;

      default:
        Serial.println("Error: unknown command.");
        break;
    }

    memset(frequencyString, 0, sizeof(frequencyString));
    inputByte = 0;
    bufferPosition = 0;
  }
}

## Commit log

2022-10-28 Delete Filter Frequency Response Visualizer directory
    Reuploading with .Net 4.7.2 FFRV
2022-10-28 Adding Files
    New framework upload 4.7.2
2022-11-10 Threading and Plotting logic
2022-11-11 Corrected Arduino Logic
2023-02-03 Add files via upload
    Successful sweep with Arduino code using this library.
2023-02-17 Additional - tested with current push.
2023-02-18 Add MAS and PAS v1
    Prototype boards for the MAS and PAS are added in this commit.
    The MAS board has the incorrect op amps selected, and will need
    to be updated for a later commit
    [PAS.kicad_pcb, PAS.sch, Peak Detector.kicad_pcb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]
2023-02-19 Update OpAmp footprint on MAS PCB
    Updated the opamp on the KiCAD PCB for the MAS. Might need to
    update the diodes as well. Should look into that before ordering
    version 1.1 of this board
    [Peak Detector.kicad_pcb, Peak Detector.sch]
2023-02-20 Reconnect peak_in to positive op amp terminal
    [PAS.kicad_pcb, Peak Detector.kicad_pcb, Peak Detector.sch]
2023-02-21 Lint - remove extra v- net
    [Peak Detector.sch]
2023-02-21 Add power breakout board schematic/PCB
    [powerbreakout.kicad_pcb, powerbreakout.sch]
2023-02-21 Add power graphic
    [powerbreakout.kicad_pcb]
2023-03-03 Create breakout board for switch
    Give to Mark so he may print
    [SwitchPCB.kicad_pcb, SwitchPCB.sch]
2023-03-05 Increase trace widths for SwitchPCB
    Increase trace widths as per the suggestion of Mark so that way the
    board can be more easily manufactured in the senior design lab
    [SwitchPCB.kicad_pcb]
2023-03-08 Refresh button, readme, requirements.
2023-03-09 Averaging dynamically and Voltage conversion
2023-03-11 Add 2 more mounting holes
    [powerbreakout.kicad_pcb]
2023-03-11 Add silkscreens
    [Peak Detector.kicad_pcb, powerbreakout.kicad_pcb]
2023-04-06 Add Arduino script from Firmware-Tests
2023-04-07 Add Arduino main from branch Firmware_Tests
2023-04-07 Add LED indicator functionality
2023-04-07 Remove WOS frequency reset
    Removed due to the fact that there was a DC curve when starting a new
    sweep with the newly implemented level shifter.
    [FFRV_Variable_Read.ino]
2023-04-07 Add analogSetup(); to setup to activate ADC
2023-04-07 Fix math in application, testing changes
    [FFRV_Variable_Read.ino, ffrv.py]
2023-04-18 Added kiCAD full board files and misc code
    [FFRV_PCB_V1-B_Cu.gbr, FFRV_PCB_V1-B_Mask.gbr, FFRV_PCB_V1-B_Paste.gbr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]
